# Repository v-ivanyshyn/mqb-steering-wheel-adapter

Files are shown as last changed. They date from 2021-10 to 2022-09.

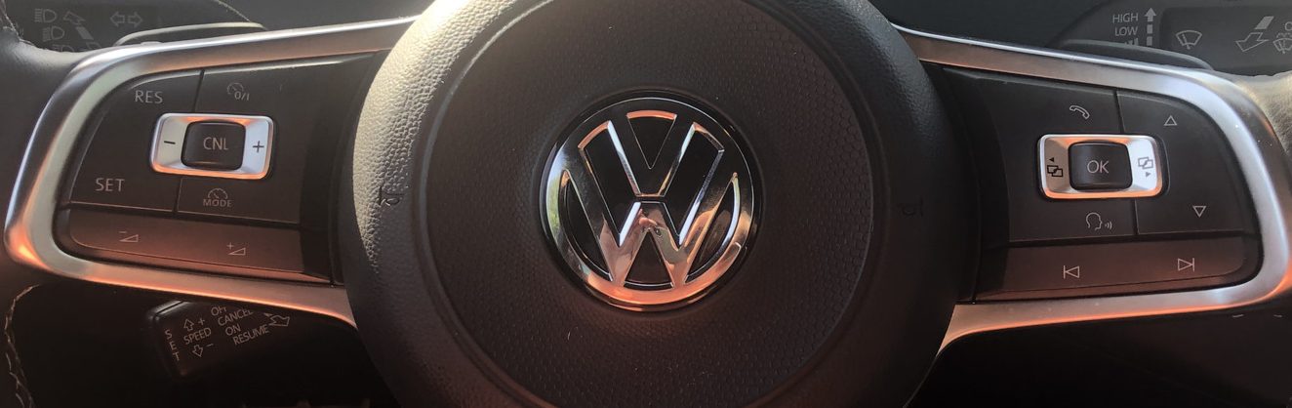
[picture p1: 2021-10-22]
firmwares/acc timer, cnl/img2.png

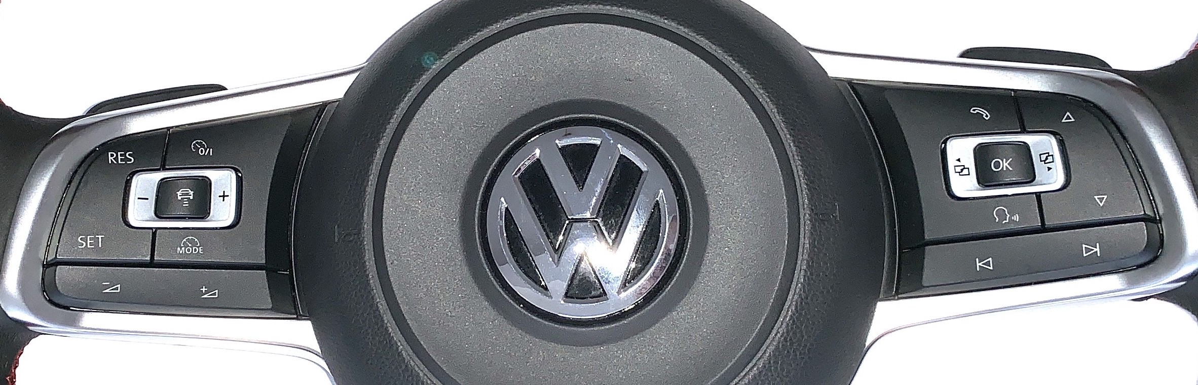
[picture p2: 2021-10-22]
firmwares/no acc, phone/img.jpg

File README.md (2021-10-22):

# MQB steering wheel adapter
*(retrofit MQB steering wheel into PQ46 platform - VW Passat b6/b7, CC)*

The adapter supports on-wheel buttons (media and cruise control). Under the hood it intercepts LIN bus between the steering control unit and the buttons on the wheel. It converts pressed button code from MQB to PQ, accepable by the steering control unit. Also it replaces cruise control lever, converting pressed buttons code on the wheel into the lever signals.

## What versions of steering control units and wheels are supported?
Basically any steering control unit of PQ46 platform that supports on-wheel buttons and cruise control. And steering wheels of MQB platform which match the images in 'firmwares' directory.

The hardware part is based on Arduino Pro Mini (16MHz 5V) and uses couple of optocouplers, LIN transmitters and resistors to fit into car's interface. I share Gerber files, list of components and installation manual.

Software is presented as compiled firmware files. The firmwares are different depending on the steering wheen buttons.

## How to assemble the adapter:
- buy the following parts:
  - Arduino Pro Mini 16MHz 5V
  - 2 optocouplers LTV-847S
  - 2 LIN transmitters MCP2003A-E/SN
  - 5V voltage regulator L7805CV
  - 2 100R resistors in 1206 SMD package
  - 2 150R resistors in 1206 SMD package
  - 1 180R resistor in 1206 SMD package
  - 3 240R resistors in 1206 SMD package
  - 8 330R resistors in 1206 SMD package
  - 3 390R resistors in 1206 SMD package
  - 1 4K7 resistor in 1206 SMD package
  - 2-pin 2.54mm Dupont Connector (https://www.aliexpress.com/item/32905764355.html)
  - 6-pin Edge Card Connector Slot 2.54 Mm Pitch (https://www.aliexpress.com/item/4000573796772.html) - You'll have to cut down 6-pin connector to fit it into the steering control unit nest, or you can skip this item and reuse a connector from your factory cruise control lever
- make the PCB based on the Gerber files
- solder all stuff to get this result:

adapter front
adapter rear

## How to burn a firmware:
- first, find the firmware fitting your steering wheel buttons. Look through images in each firmware directory
- upload the firmware to Arduino using any available programmator

### Follow the manual to install the adapter into your car:
https://github.com/v-ivanyshyn/mqb-steering-wheel-adapter/blob/main/Manual%20EN.pdf

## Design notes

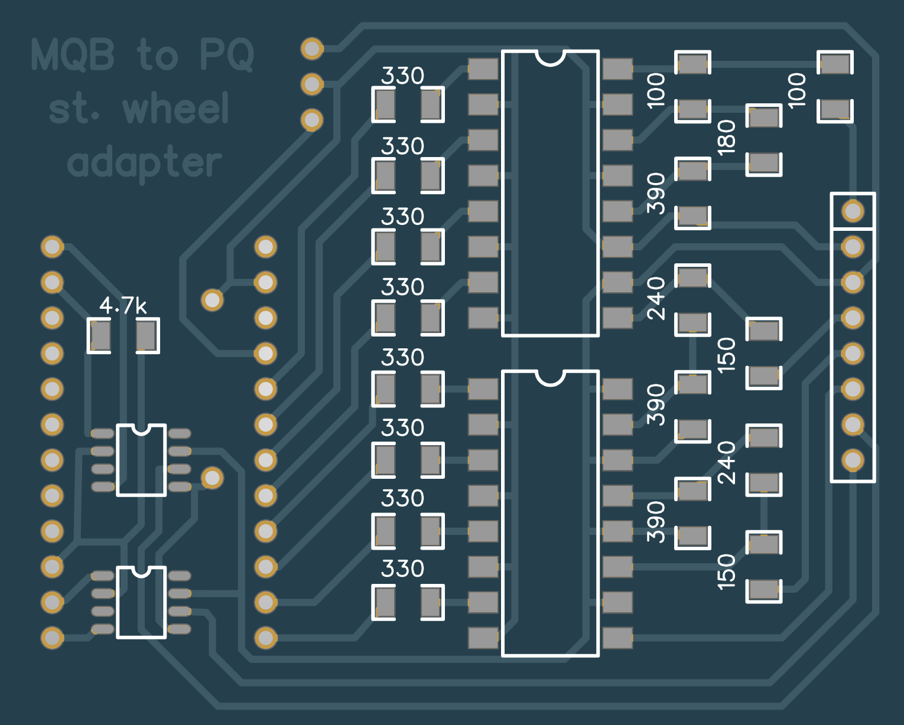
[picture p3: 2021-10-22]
pcb.png

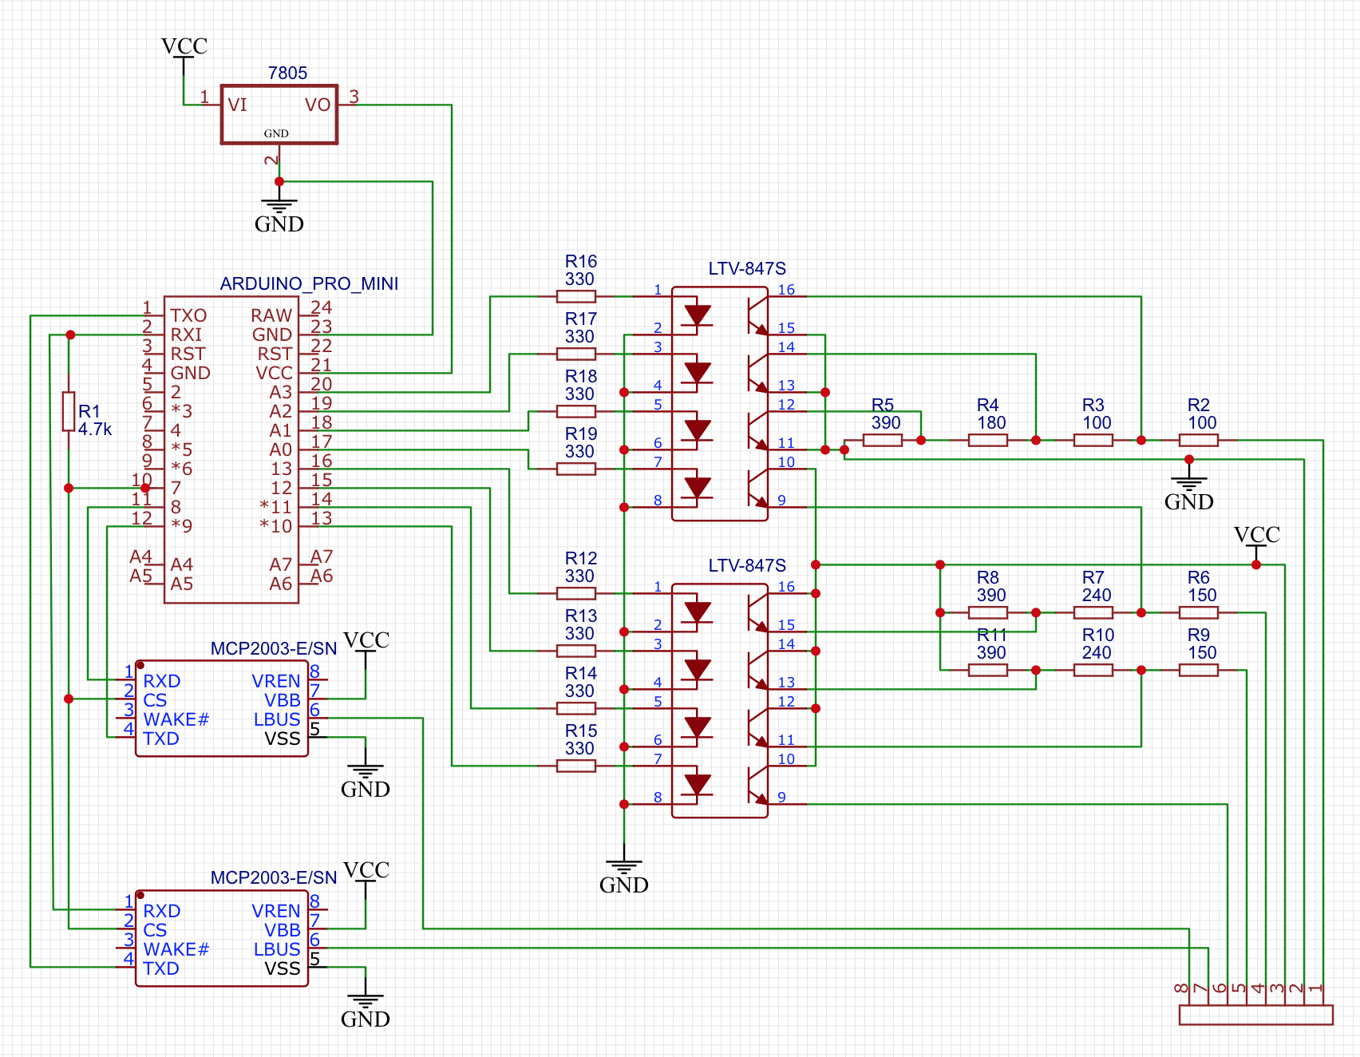
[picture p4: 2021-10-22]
circuit.png

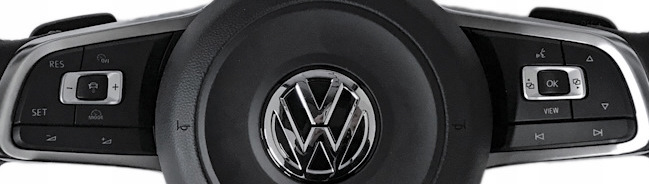
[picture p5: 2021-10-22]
firmwares/acc, view/img.jpg

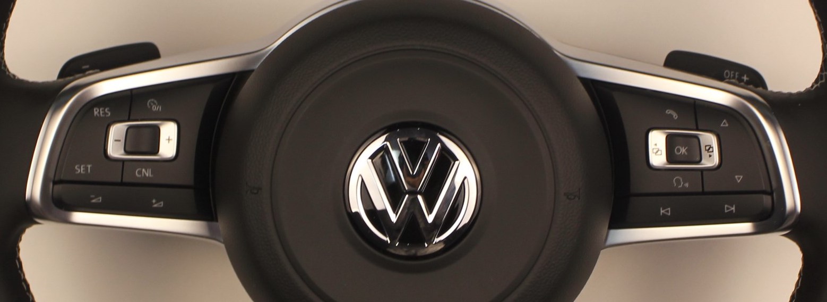
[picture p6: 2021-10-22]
firmwares/no acc, cnl/img.jpg

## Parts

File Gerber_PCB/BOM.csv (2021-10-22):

ID | Name | Designator | Footprint | Quantity | Manufacturer Part | Manufacturer | Supplier | Supplier Part | LCSC Assembly
1 | MCP2003-E/SN | U7,U4 | SOIC-8_L5.0-W4.0-P1.27-LS6.0-BL | 2 | MCP2003-E/SN | Microchip Tech | LCSC | C220607
2 | 7805 | U3 | TO220H | 1
3 | 240 | R7,R10 | R1206 | 2
4 | 390 | R8,R11,R5 | R1206 | 3
5 | 150 | R9,R6 | R1206 | 2
6 | 4.7k | R1 | R1206 | 1
7 | 330 | R12,R13,R15,R16,R17,R18,R19,R14 | R1206 | 8
8 | 100 | R2,R3 | R1206 | 2
9 | 180 | R4 | R1206 | 1
10 | LTV-847S | U5,U6 | SMD-16_L20.0-W6.5-P2.54-LS10.2-BL | 2 | LTV-847S | LITEON | LCSC | C114599 | Yes

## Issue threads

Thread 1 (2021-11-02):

Short Questions about Timing etc

EliasKotlyar, 2021-11-02:
Hello @v-ivanyshyn

I am currently tinkering around with my new steering wheel(VW Golf 7 Sport Steering Wheel) and trying to adopt it to my PQ35 Car (VW EOS 2008). I stumbled across your project and need to express my gratitude. It really helps to see an implementation! Before i was using certain blog-posts for getting some results.

It would really help if you could answer my questions:
1. My Steering Wheel looks different to the ones described in "firmwares". It has a button with a "shacking car" instead of "CNL" Button. Does it need special LIN-IDs/something different to drive it? Here is a picture:
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

2. I am currently sending different LIN-IDs to poll it with following timings:
RTR Message - 0x0F - every 100ms
RTR Message - 0x0E - every 100ms
Normal Message - 0x0F with Payload (0x1A ,0xF9, 0xFF,0xFF) - every 200ms

However the background stays off and there is no change in messages. I am getting following messages:

**0x0F:**
```
  sllin0       00F   [0]  remote request
  sllin0       00F   [8]  F4 41 80 2A 00 00 00 00
  sllin0       00F   [0]  remote request
  sllin0       00F   [8]  50 42 80 2A 00 00 00 00
  sllin0       00F   [0]  remote request
  sllin0       00F   [8]  08 43 80 2A 00 00 00 00
  sllin0       00F   [0]  remote request
  sllin0       00F   [8]  88 44 80 2A 00 00 00 00
  sllin0       00F   [0]  remote request
  sllin0       00F   [8]  2D 45 80 2A 00 00 00 00
  sllin0       00F   [0]  remote request
  sllin0       00F   [8]  34 46 80 2A 00 00 00 00
  sllin0       00F   [0]  remote request
  sllin0       00F   [8]  11 47 80 2A 00 00 00 00
```

**0x0E:**
```
  sllin0       00E   [0]  remote request
  sllin0       00E   [8]  90 00 00 00 90 00 00 00
  sllin0       00E   [0]  remote request
  sllin0       00E   [8]  81 00 00 00 90 00 00 00
  sllin0       00E   [0]  remote request
  sllin0       00E   [8]  92 00 00 00 90 00 00 00
  sllin0       00E   [0]  remote request
  sllin0       00E   [8]  83 00 00 00 90 00 00 00
  sllin0       00E   [0]  remote request
  sllin0       00E   [8]  94 00 00 00 90 00 00 00
  sllin0       00E   [0]  remote request
  sllin0       00E   [8]  85 00 00 00 90 00 00 00
  sllin0       00E   [0]  remote request
  sllin0       00E   [8]  86 00 00 00 90 00 00 00
  sllin0       00E   [0]  remote request
  sllin0       00E   [8]  87 00 00 00 90 00 00 00
  sllin0       00E   [0]  remote request
  sllin0       00E   [8]  88 00 00 00 90 00 00 00
  sllin0       00E   [0]  remote request
  sllin0       00E   [8]  89 00 00 00 90 00 00 00
  sllin0       00E   [0]  remote request
  sllin0       00E   [8]  8A 00 00 00 90 00 00 00
  sllin0       00E   [0]  remote request
  sllin0       00E   [8]  8B 00 00 00 90 00 00 00
```
It does not matter if i press some button or not, it does not change anything. Also if i send 0x0F with payload, it does not light up

Any Idea how i can get it working? Am i missing something?
My code can be found here:
https://github.com/EliasKotlyar/MQB-SteeringWheel

Many thanks in Advance
Greatings
Elias

Georgy-Garnov, 2021-11-12:
Exists code in your repository did not provide clear vision how is it working.
Which device are you using?
`can.interface.Bus(channel="sllin0", bustype="socketcan")`
what is this stack/class? how is it workinп? Why is it called CAN but not LIN?
Did transfer for LIN starts with SYNC 0x55?
But since you getting answers it seems that it's working.
Maybe there is some wrong connections with steering wheel? No power on some pin for example?
Also you can try to query other responders not only 0x0F, 0x0E. Also you have error in sending Light data it's ID is 0x0D not 0x0F.

EliasKotlyar, 2021-11-12:
@Georgy-Garnov: I figured it out by now. My hardware which i was using was an macchina p1, which is a linux based device having automotive interfaces. I was using the default implementation of lin-bus called "linux-lin" based on socketcan. Thats why its confusing with "can" and "lin". The library should be responsible for all checksum calculations etc. However it turned out that the library is not very stable, so i stopped progress on that.

I was able to make it run on a ESP32 Board which had the interfaces already applied. My implementation can be found here:
https://github.com/EliasKotlyar/MQB-SteeringWheel/tree/master/esp32/MQB-SteeringWheel/src

Its basically the same - I am using a different LIN-Library so i could use a more modular approach. I want to do the same on a PQ35 Golf 5 Platform, and considering using CAN-Messages instead of Opto-Couplers.

@v-ivanyshyn Many thanks for sharing this library!

Closed 2021-11-14.

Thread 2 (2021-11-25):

Compiling Errors

gekomod, 2021-11-25:
'''invalid conversion from 'int' to 'lib_bus_mqb::<unnamed enum>' [-fpermissive]'''

'''} pressed_acc_button = 0;'''

File -lin-bus-mqb.h

gekomod, 2021-12-18:
And redy pcb with all components dosent work ground not have and lbus :( 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

Closed 2022-01-18.

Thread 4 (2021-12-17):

Writing to arduino

rhinopower85, 2021-12-17:
Should it be possible to write to the arduino when mounted to the board?

i have built one up, but didn’t preprogram it. Others I have as bare arduino boards but not the one I have fitted

thanks

gekomod, 2021-12-18:
use usbtiny programmer, I used Visual Studio Code and platform.io there is a compilation error but this is how programming through arduino does not work for me myself.

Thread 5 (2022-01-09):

Not working with mqb Sterling

gekomod, 2022-01-09:
Hi not working with mqb Stering 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

Firmware is write with usbtiny but key is not work i'm installed with manual

gekomod, 2022-01-10:
my error ltv was the other way around, but it does not change the fact that there is no steering wheel and there is no reaction, only the cruise control will light up for a moment on the meter and that's it

Closed 2022-01-18.

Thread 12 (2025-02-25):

Octavia II  PQ-MQB steering wheel firmware

KaszDavid, 2025-02-25:
Hi everyone, I have an Octavia MK2 (A5) PQ35 in which I installed an Octavia IV steering wheel. My question is, can you create firmware for it so that it works with Skoda as well?

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

nero150, 2025-05-18:
I'm joining in, I need firmware for this steering wheel

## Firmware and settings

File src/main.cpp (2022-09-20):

#define LIN_PQ 1
#define LIN_MQB 1
#define DEBUG_SERIAL 1
const int DEBUG_PQ = 0;
const int DEBUG_MQB = 0;
const int DEBUG_ACC = 3;

#include <Arduino.h>
#include <EEPROM.h>
#define EEPROM_ACC_ON_ADDRESS 0
#if DEBUG_SERIAL
#include <SoftwareSerial.h>
SoftwareSerial debug_serial(/*rx*/3, /*tx*/2);
#endif
#if DEBUG_SERIAL
#define DebugLog debug_serial.print
#else
#define DebugLog(...)
#endif
#if LIN_PQ
#include "lin-bus-pq.h"
lib_bus_pq linPq;
#endif
#if LIN_MQB
#include "lin-bus-mqb.h"
#if defined(__AVR_ATmega328P__)
lib_bus_mqb linMqb(8, 9, 7);
#elif defined(__AVR_ATmega32U4__)
lib_bus_mqb linMqb(4, 9, 5);
#endif
#endif
#include "acc-handle.h"

struct {
    uint8_t pq_id;
    uint8_t mqb_id;
} buttons[] = {
// MQB right side:
    {0x00, 0x00},
    {0x03, 0x16}, // prev
    {0x02, 0x15}, // next
    {0x1A, 0x19}, // phone <- voice/mic
    {0x1A, 0x1C}, // phone
    {0x29, 0x23}, // return <- view (on wheels with "view" button)
    {0x22, 0x04}, // up
    {0x23, 0x05}, // down
    {0x09, 0x03}, // src-
    {0x0A, 0x02}, // src+
    {0x28, 0x07}, // ok
    // 'return' on PQ not assigned to MQB: 0x29
// MQB left side:
    {0x06, 0x10}, // vol+
    {0x07, 0x11}, // vol-
    {0x2B, 0x0C}, // voice/mic <- ACC mode (on wheels with "view" button)
};

void setup() {
#if DEBUG_SERIAL
    debug_serial.begin(115200);
    DebugLog("\nSetup...");
#endif
    accHandle.setup();
#if LIN_PQ
    linPq.setup();
#endif
#if LIN_MQB
    linMqb.setup();
#endif
}

void loop() {
    static unsigned long time = millis();
#if LIN_PQ
    int linPqStatus = linPq.loop();
#elif LIN_MQB
    bool light_on = (time / 1000) % 2;
    linMqb.forceLightData(light_on);
#endif
#if LIN_MQB
    int linMqbStatus = linMqb.loop();
#endif
#if LIN_PQ && LIN_MQB
    memcpy(linMqb.light_data, linPq.light_data, 4);
    linPq.pressed_button = linMqb.pressed_button;
    linPq.pressed_gear_shifter = linMqb.pressed_gear_shifter;
    linPq.pressed_horn = linMqb.pressed_horn;
    for (unsigned int i=0; i<sizeof(buttons) / sizeof(buttons[0]); i++) {
        if (buttons[i].mqb_id == linMqb.pressed_button) {
            linPq.pressed_button = buttons[i].pq_id;
            break;
        }
    }

#endif
#if LIN_MQB
    accHandle.loop(linMqb.pressed_acc_button, linMqb.temperature_sensor);
#endif
    time = millis();
}

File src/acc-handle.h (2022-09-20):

#define ACC_ON_BTN lib_bus_mqb::ACC_OFF
#define ACC_MODE_BTN lib_bus_mqb::ACC_MODE

class AccHandle {
#if defined(__AVR_ATmega328P__)
    const uint8_t ACC_ON_PIN = 10;
    const uint8_t ACC_SPEED_PLUS_PIN = 11;
    const uint8_t ACC_SPEED_MINUS_PIN = 12;
    const uint8_t ACC_RESUME_PIN = A0;
#elif defined(__AVR_ATmega32U4__)
    const uint8_t ACC_ON_PIN = 10;
    const uint8_t ACC_SPEED_PLUS_PIN = 16;
    const uint8_t ACC_SPEED_MINUS_PIN = 14;
    const uint8_t ACC_RESUME_PIN = 15;
#endif
    const uint8_t ACC_CANCEL_PIN = 13;
    const uint8_t ACC_DIST_PLUS_PIN = A1;
    const uint8_t ACC_DIST_MINUS_PIN = A2;
    const uint8_t ACC_SET_PIN = A3;
    const uint8_t WHEEL_HEAT_PIN = 5;
    // Отключение подогрева при достижении рулем 30 град. цельсия
    // [Температура в град. цельсия] = [значения с датчика] - 68.
    const uint8_t WHEEL_TEMPERATUR_OFF = 0x62;
public:
    bool accOn = false;
    bool wheelHeatOn = false;
    unsigned long modePressedTimer;
    unsigned long distPressedTimer;
    unsigned long wheelHeatTimer;
    void setup() {
        pinMode(ACC_ON_PIN, OUTPUT);
        pinMode(ACC_RESUME_PIN, OUTPUT);
        pinMode(ACC_CANCEL_PIN, OUTPUT);
        pinMode(ACC_SPEED_PLUS_PIN, OUTPUT);
        pinMode(ACC_SPEED_MINUS_PIN, OUTPUT);
        pinMode(ACC_DIST_PLUS_PIN, OUTPUT);
        pinMode(ACC_DIST_MINUS_PIN, OUTPUT);
        pinMode(ACC_SET_PIN, OUTPUT);
        pinMode(WHEEL_HEAT_PIN, OUTPUT);
        accOn = EEPROM.read(EEPROM_ACC_ON_ADDRESS);
        distPressedTimer = 0;
        modePressedTimer = 0;
        wheelHeatTimer = 0;
    }

    void loop(uint8_t pressedAccButton, uint8_t temperatureSensor) {
#if LIN_MQB
        static unsigned long time = millis();
        time = millis();
        static uint8_t prevAccOnPressed = false;
        if ((pressedAccButton == ACC_ON_BTN) && !prevAccOnPressed) {
            prevAccOnPressed = true;
            accOn = !accOn;
            EEPROM.write(EEPROM_ACC_ON_ADDRESS, accOn);
            if (DEBUG_ACC == 1) DebugLog(accOn ? "ON  " : "OFF ");
        }
        else if (pressedAccButton != ACC_ON_BTN) {
            prevAccOnPressed = false;
        }
        if (pressedAccButton == lib_bus_mqb::ACC_DIST) {
            distPressedTimer = millis() + 1000;
        }
        if ((distPressedTimer > time) && ((pressedAccButton == lib_bus_mqb::ACC_PLUS) || (pressedAccButton == lib_bus_mqb::ACC_MINUS))) {
            distPressedTimer = millis() + 1000;
        }
        if (pressedAccButton != 0 && pressedAccButton != ACC_ON_BTN && pressedAccButton != ACC_MODE_BTN && !accOn) {
            accOn = true;   // automatically turn ACC on if any button pressed
            EEPROM.write(EEPROM_ACC_ON_ADDRESS, accOn);
            if (DEBUG_ACC == 1) DebugLog(accOn ? "ACC ON" : "ACC OFF");
        }
        // Track MODE button long pressed for switching wheel heater
        if (pressedAccButton == ACC_MODE_BTN) {
            if (modePressedTimer == 0) {
                // Mode button must be pressed for 2 seconds for sweetching wheel heater
                modePressedTimer = millis() + 2000;
            }
            else if ((modePressedTimer > 1) && (modePressedTimer < time)) {
                modePressedTimer = 1;
                wheelHeatOn = !wheelHeatOn;
                if (wheelHeatOn) {
                    // set wheel heater timer for 5 minutes. Automatically turn wheel heater off after that time.
                    wheelHeatTimer = millis() + 300000;
                } else {
                    wheelHeatTimer = 0;
                }
                if (DEBUG_ACC == 3) {
                    DebugLog(wheelHeatOn ? "Wheel heater ON \n" : "Wheel heater OFF \n");
                }
            }
        } else if (pressedAccButton != ACC_MODE_BTN) {
            modePressedTimer = 0;
        }
        // Отключение подогрева руля по температуре
        if (wheelHeatOn && (temperatureSensor >= WHEEL_TEMPERATUR_OFF)) {
            wheelHeatTimer = 0;
            wheelHeatOn = 0;
            if (DEBUG_ACC == 3) {
                DebugLog("Wheel heater OFF by temperature \n");
            }
        }
        // Automatically turn of wheel heater after 5 minutes
        if (wheelHeatOn && (wheelHeatTimer < time)) {
            wheelHeatTimer = 0;
            wheelHeatOn = 0;
            if (DEBUG_ACC == 3) {
                DebugLog("Wheel heater OFF by timer \n");
            }
        }
        uint8_t ACC_ON = accOn ? HIGH : LOW;
        uint8_t ACC_RESUME = (pressedAccButton == lib_bus_mqb::ACC_RESUME) ? HIGH : LOW;
        uint8_t ACC_CANCEL = HIGH;//!accOn || (pressedAccButton == lib_bus_mqb::ACC_DIST) ? LOW : HIGH;
        uint8_t ACC_SPEED_PLUS = (distPressedTimer < time) && (pressedAccButton == lib_bus_mqb::ACC_PLUS) ? HIGH : LOW;
        uint8_t ACC_SPEED_MINUS = (distPressedTimer < time) && (pressedAccButton == lib_bus_mqb::ACC_MINUS) ? HIGH : LOW;
        uint8_t ACC_DIST_PLUS = (distPressedTimer > time) && (pressedAccButton == lib_bus_mqb::ACC_PLUS) ? HIGH : LOW;
        uint8_t ACC_DIST_MINUS = (distPressedTimer > time) && (pressedAccButton == lib_bus_mqb::ACC_MINUS) ? HIGH : LOW;
        uint8_t ACC_SET = (pressedAccButton == lib_bus_mqb::ACC_SET) ? HIGH : LOW;
        uint8_t WHEEL_HEAT = wheelHeatOn ? HIGH : LOW;
        digitalWrite(ACC_ON_PIN, ACC_ON);
        digitalWrite(ACC_RESUME_PIN, ACC_RESUME);
        digitalWrite(ACC_CANCEL_PIN, ACC_CANCEL);
        digitalWrite(ACC_SPEED_PLUS_PIN, ACC_SPEED_PLUS);
        digitalWrite(ACC_SPEED_MINUS_PIN, ACC_SPEED_MINUS);
        digitalWrite(ACC_DIST_PLUS_PIN, ACC_DIST_PLUS);
        digitalWrite(ACC_DIST_MINUS_PIN, ACC_DIST_MINUS);
        digitalWrite(ACC_SET_PIN, ACC_SET);
        digitalWrite(WHEEL_HEAT_PIN, WHEEL_HEAT);
        // if (DEBUG_ACC == 2) {
        //     DebugLog("\nACC handle: ");
        //     DebugLog("BTN: "); DebugLog(pressedAccButton, HEX); DebugLog(" "); 
        //     DebugLog(ACC_ON ? "ON  " : "OFF ");
        //     DebugLog(ACC_RESUME ? "RESUME " : "");
        //     DebugLog(ACC_CANCEL ? "CANCEL " : "");
        //     DebugLog(ACC_SPEED_PLUS ? "SPD+ " : "");
        //     DebugLog(ACC_SPEED_MINUS ? "SPD- " : "");
        //     DebugLog(ACC_DIST_PLUS ? "DIST+ " : "");
        //     DebugLog(ACC_DIST_MINUS ? "DIST- " : "");
        //     DebugLog(ACC_SET ? "SET " : "");
        // }
#endif
    }
} accHandle;

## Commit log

2021-10-22 Add files via upload
    Initial commit
    [BOM.csv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]
2021-11-02 Add files via upload
    Sources (for a variant of the wheel with 'view' button)
2021-11-11 added support for horn button trunsfer via LIN
2021-11-14 Реализована функция переключения подогрева руля
2021-11-16 Добавлен таймер для автоматического отключения подогрева руля
2021-11-19 Управление подогревом руля по показаниям датчика температуры
